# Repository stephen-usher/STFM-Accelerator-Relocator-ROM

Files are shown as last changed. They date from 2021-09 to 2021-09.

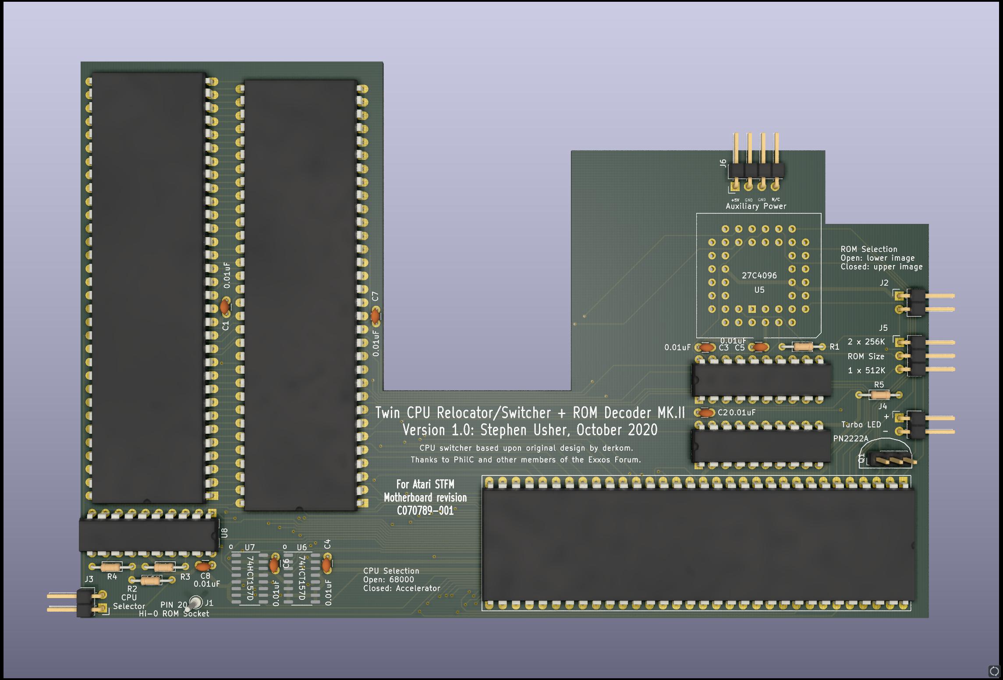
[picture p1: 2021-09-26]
STFM-TF536-Relocator+ROM-MkII.jpg

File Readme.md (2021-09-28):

This project is a PCB to allow two CPU sockets to be switched between on an
Atari ST.

It also provides a socket for a 512K ROM which can either be presented as a
single image or switched between an upper or lower image along with the logic
required to enable the larger ROMs, such as TOS 2.06 on a standard machine.

The ROM switching circuit was borrowed from Derkom (on the Exxos Forum) which
he used on his re-locator/switcher board for his STacy project.

The two sockets are identical so either can hold any processor which runs in a
68000 socket. On mine I currently had a stock 68000 in the "68000" socket and
a TF536 in the "Accelerator" one.

The ROM socket is compatible with the Exxos dual TOS ROMs.

P.S. There is another very important feature... there's a Turbo LED header,
which will light an LED if the "Accelerator" socket is in use.

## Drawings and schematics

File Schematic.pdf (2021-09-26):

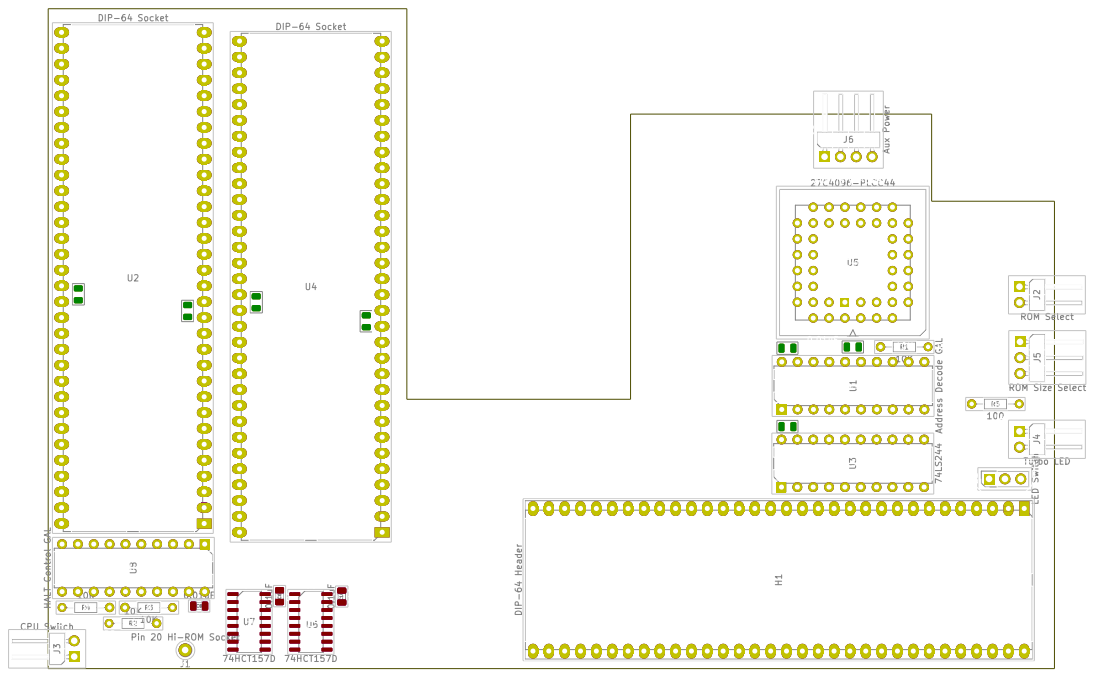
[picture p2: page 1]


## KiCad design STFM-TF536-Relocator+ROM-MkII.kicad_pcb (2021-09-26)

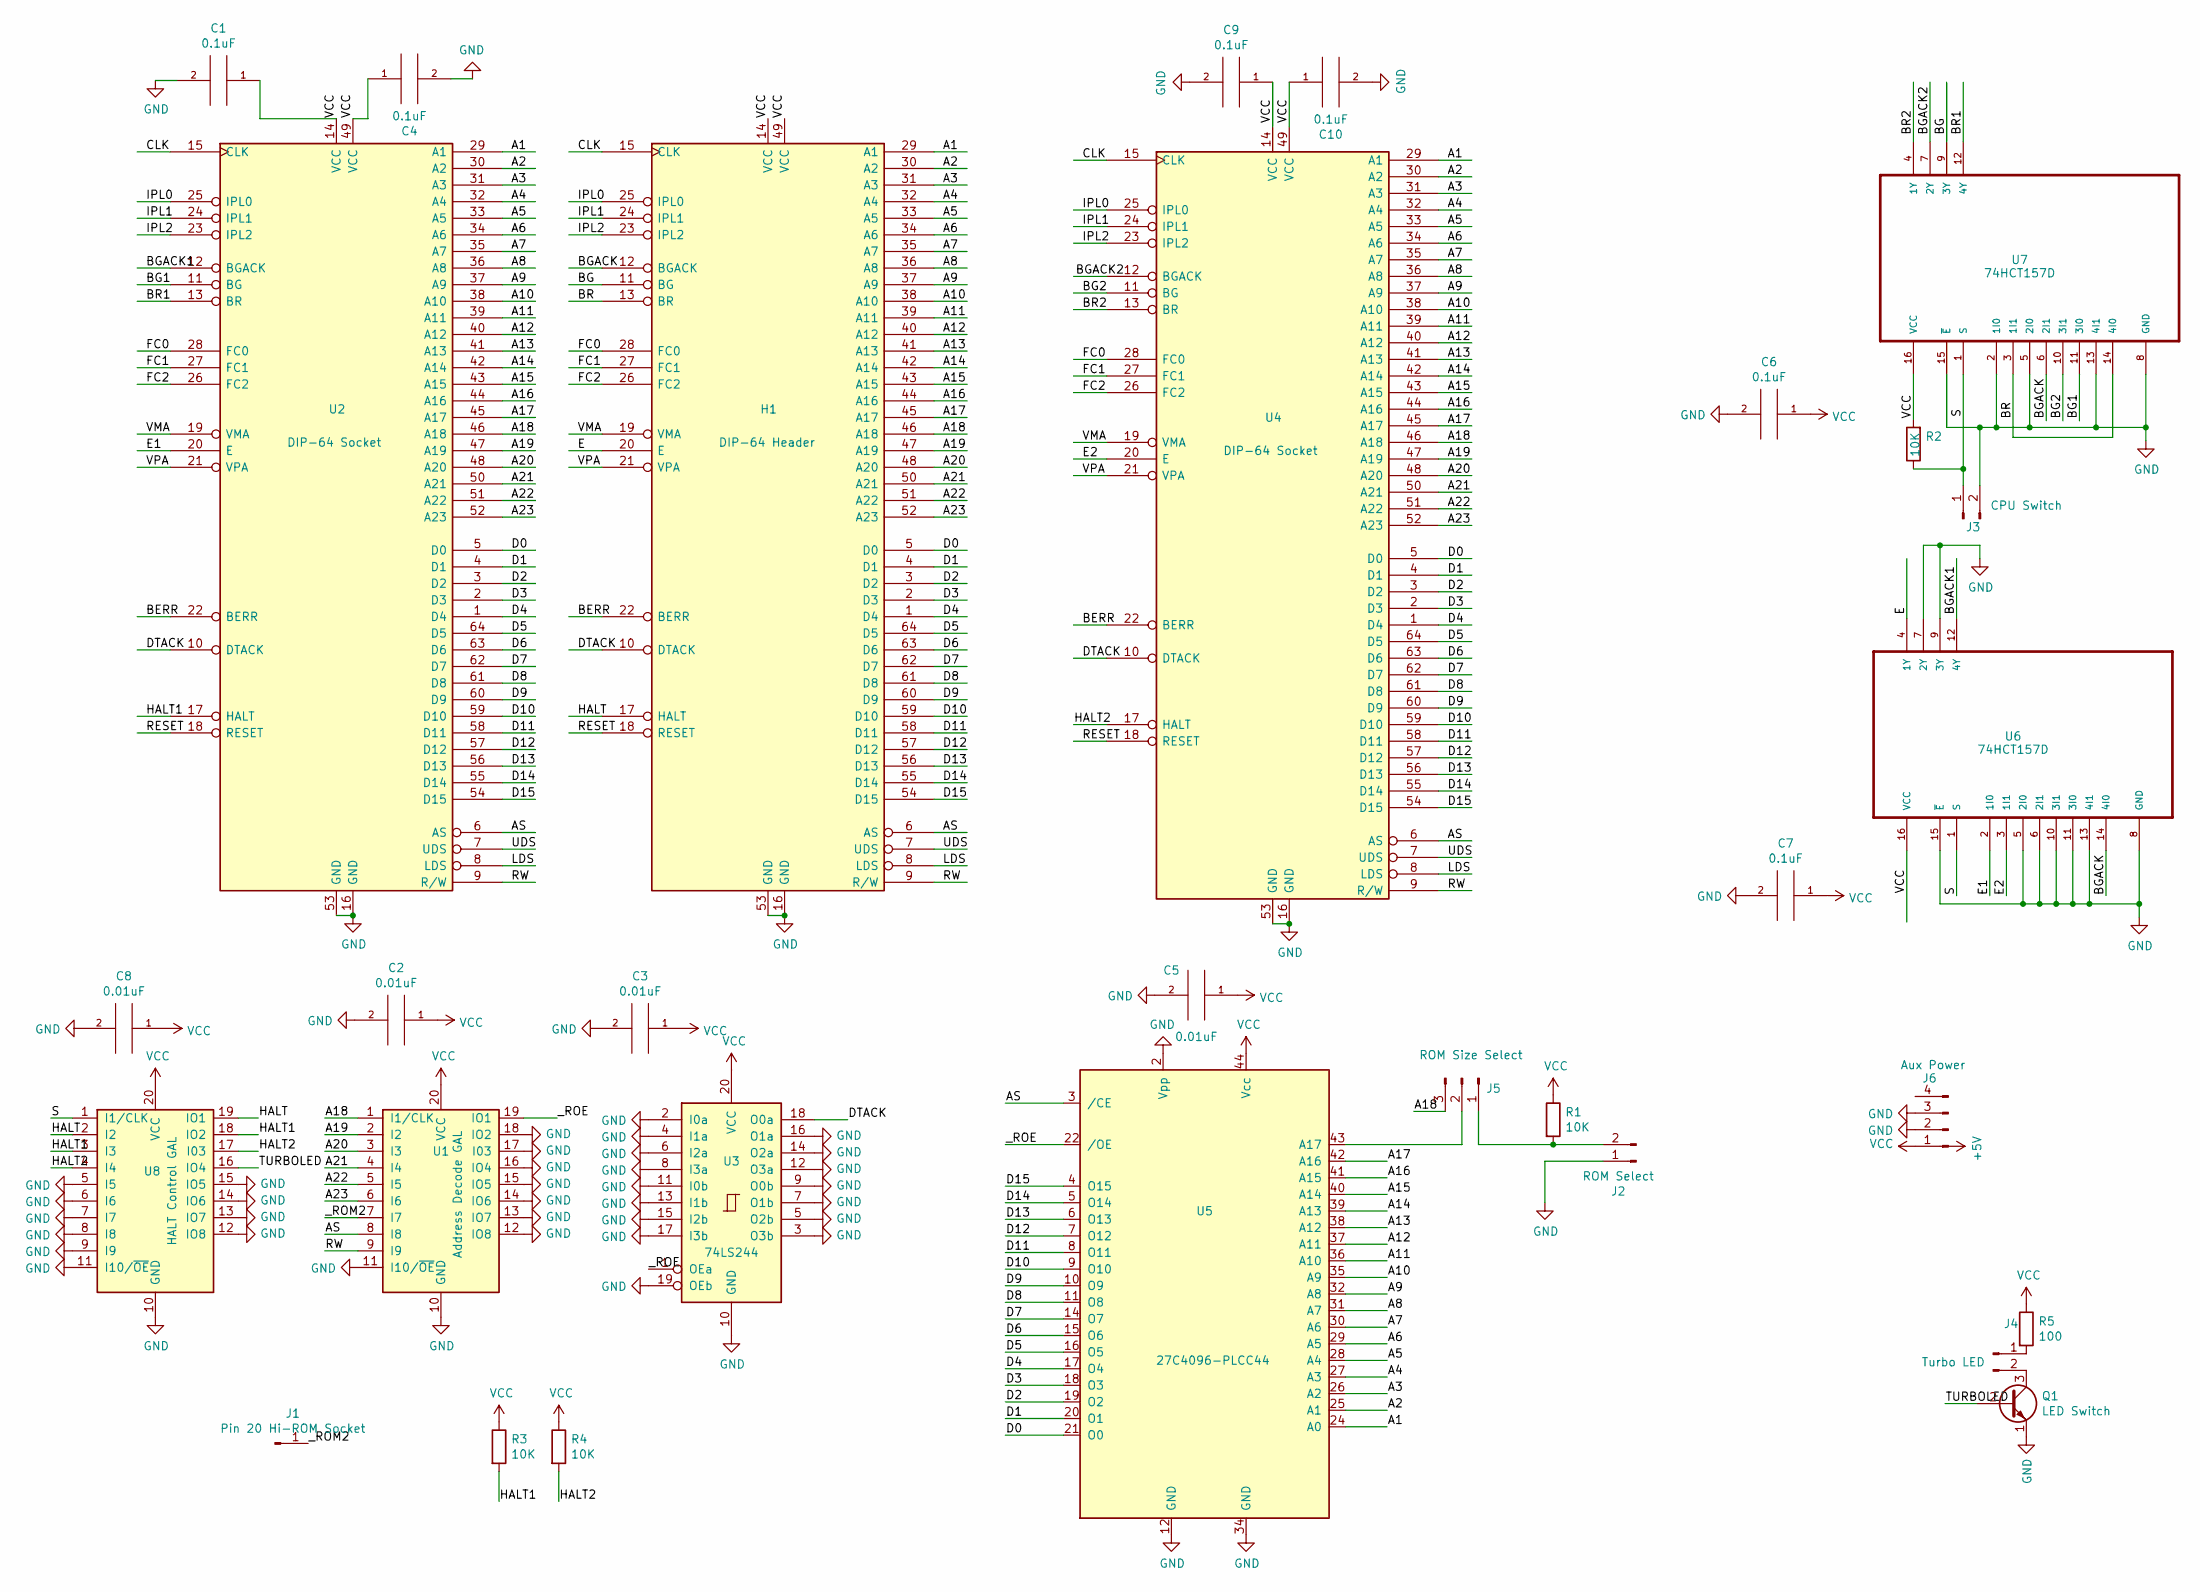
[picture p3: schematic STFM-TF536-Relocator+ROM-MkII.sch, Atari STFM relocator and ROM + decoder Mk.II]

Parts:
C1, C4, C6, C7, C9, C10: 0.1uF; C_0805_2012Metric
C2, C3, C5, C8: 0.01uF; C_0805_2012Metric
H1: DIP-64 Header; DIP-64_W22.86mm_Socket_LongPads
J1: Pin 20 Hi-ROM Socket; Pin_D1.0mm_L10.0mm
J2: ROM Select; PinHeader_1x02_P2.54mm_Horizontal
J3: CPU Switch; PinHeader_1x02_P2.54mm_Horizontal
J4: Turbo LED; PinHeader_1x02_P2.54mm_Horizontal
J5: ROM Size Select; PinHeader_1x03_P2.54mm_Horizontal
J6: Aux Power; PinHeader_1x04_P2.54mm_Horizontal
Q1: LED Switch; PinHeader_1x03_P2.54mm_Vertical
R1, R2, R3, R4: 10K; R_Axial_DIN0204_L3.6mm_D1.6mm_P7.62mm_Horizontal
R5: 100; R_Axial_DIN0204_L3.6mm_D1.6mm_P7.62mm_Horizontal
U1: Address Decode GAL; DIP-20_W7.62mm
U2, U4: DIP-64 Socket; DIP-64_W22.86mm_LongPads
U3: 74LS244; DIP-20_W7.62mm
U5: 27C4096-PLCC44; PLCC-44_THT-Socket
U6, U7: 74HCT157D; SO-16_3.9x9.9mm_P1.27mm
U8: HALT Control GAL; DIP-20_W7.62mm

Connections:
/A1: H1.29 (A1), U2.29 (A1), U4.29 (A1), U5.24 (A0)
/A2: H1.30 (A2), U2.30 (A2), U4.30 (A2), U5.25 (A1)
/A3: H1.31 (A3), U2.31 (A3), U4.31 (A3), U5.26 (A2)
/A4: H1.32 (A4), U2.32 (A4), U4.32 (A4), U5.27 (A3)
/A5: H1.33 (A5), U2.33 (A5), U4.33 (A5), U5.28 (A4)
/A6: H1.34 (A6), U2.34 (A6), U4.34 (A6), U5.29 (A5)
/A7: H1.35 (A7), U2.35 (A7), U4.35 (A7), U5.30 (A6)
/A8: H1.36 (A8), U2.36 (A8), U4.36 (A8), U5.31 (A7)
/A9: H1.37 (A9), U2.37 (A9), U4.37 (A9), U5.32 (A8)
/A10: H1.38 (A10), U2.38 (A10), U4.38 (A10), U5.35 (A9)
/A11: H1.39 (A11), U2.39 (A11), U4.39 (A11), U5.36 (A10)
/A12: H1.40 (A12), U2.40 (A12), U4.40 (A12), U5.37 (A11)
/A13: H1.41 (A13), U2.41 (A13), U4.41 (A13), U5.38 (A12)
/A14: H1.42 (A14), U2.42 (A14), U4.42 (A14), U5.39 (A13)
/A15: H1.43 (A15), U2.43 (A15), U4.43 (A15), U5.40 (A14)
/A16: H1.44 (A16), U2.44 (A16), U4.44 (A16), U5.41 (A15)
/A17: H1.45 (A17), U2.45 (A17), U4.45 (A17), U5.42 (A16)
/A18: H1.46 (A18), J5.3, U1.1 (I1/CLK), U2.46 (A18), U4.46 (A18)
/A19: H1.47 (A19), U1.2 (I2), U2.47 (A19), U4.47 (A19)
/A20: H1.48 (A20), U1.3 (I3), U2.48 (A20), U4.48 (A20)
/A21: H1.50 (A21), U1.4 (I4), U2.50 (A21), U4.50 (A21)
/A22: H1.51 (A22), U1.5 (I5), U2.51 (A22), U4.51 (A22)
/A23: H1.52 (A23), U1.6 (I6), U2.52 (A23), U4.52 (A23)
/AS: H1.6 (AS), U1.8 (I8), U2.6 (AS), U4.6 (AS), U5.3 (/CE)
/BERR: H1.22 (BERR), U2.22 (BERR), U4.22 (BERR)
/BG: H1.11 (BG), U7.9 (3Y)
/BG1: U2.11 (BG), U7.11 (3I0)
/BG2: U4.11 (BG), U7.10 (3I1)
/BGACK: H1.12 (BGACK), U6.14 (4I0), U7.6 (2I1)
/BGACK1: U2.12 (BGACK), U6.12 (4Y)
/BGACK2: U4.12 (BGACK), U7.7 (2Y)
/BR: H1.13 (BR), U7.3 (1I1), U7.14 (4I0)
/BR1: U2.13 (BR), U7.12 (4Y)
/BR2: U4.13 (BR), U7.4 (1Y)
/CLK: H1.15 (CLK), U2.15 (CLK), U4.15 (CLK)
/D0: H1.5 (D0), U2.5 (D0), U4.5 (D0), U5.21 (O0)
/D1: H1.4 (D1), U2.4 (D1), U4.4 (D1), U5.20 (O1)
/D2: H1.3 (D2), U2.3 (D2), U4.3 (D2), U5.19 (O2)
/D3: H1.2 (D3), U2.2 (D3), U4.2 (D3), U5.18 (O3)
/D4: H1.1 (D4), U2.1 (D4), U4.1 (D4), U5.17 (O4)
/D5: H1.64 (D5), U2.64 (D5), U4.64 (D5), U5.16 (O5)
/D6: H1.63 (D6), U2.63 (D6), U4.63 (D6), U5.15 (O6)
/D7: H1.62 (D7), U2.62 (D7), U4.62 (D7), U5.14 (O7)
/D8: H1.61 (D8), U2.61 (D8), U4.61 (D8), U5.11 (O8)
/D9: H1.60 (D9), U2.60 (D9), U4.60 (D9), U5.10 (O9)
/D10: H1.59 (D10), U2.59 (D10), U4.59 (D10), U5.9 (O10)
/D11: H1.58 (D11), U2.58 (D11), U4.58 (D11), U5.8 (O11)
/D12: H1.57 (D12), U2.57 (D12), U4.57 (D12), U5.7 (O12)
/D13: H1.56 (D13), U2.56 (D13), U4.56 (D13), U5.6 (O13)
/D14: H1.55 (D14), U2.55 (D14), U4.55 (D14), U5.5 (O14)
/D15: H1.54 (D15), U2.54 (D15), U4.54 (D15), U5.4 (O15)
/DTACK: H1.10 (DTACK), U2.10 (DTACK), U3.18 (O0a), U4.10 (DTACK)
/E: H1.20 (E), U6.4 (1Y)
/E1: U2.20 (E), U6.2 (1I0)
/E2: U4.20 (E), U6.3 (1I1)
/FC0: H1.28 (FC0), U2.28 (FC0), U4.28 (FC0)
/FC1: H1.27 (FC1), U2.27 (FC1), U4.27 (FC1)
/FC2: H1.26 (FC2), U2.26 (FC2), U4.26 (FC2)
/HALT: H1.17 (HALT), U8.2 (I2), U8.19 (IO1)
/HALT1: R3.2, U2.17 (HALT), U8.3 (I3), U8.18 (IO2)
/HALT2: R4.2, U4.17 (HALT), U8.4 (I4), U8.17 (I03)
/IPL0: H1.25 (IPL0), U2.25 (IPL0), U4.25 (IPL0)
/IPL1: H1.24 (IPL1), U2.24 (IPL1), U4.24 (IPL1)
/IPL2: H1.23 (IPL2), U2.23 (IPL2), U4.23 (IPL2)
/LDS: H1.8 (LDS), U2.8 (LDS), U4.8 (LDS)
/RESET: H1.18 (RESET), U2.18 (RESET), U4.18 (RESET)
/RW: H1.9 (R/W), U1.9 (I9), U2.9 (R/W), U4.9 (R/W)
/S: J3.1, R2.1, U6.1 (S), U7.1 (S), U8.1 (I1/CLK)
/TURBOLED: Q1.2 (B), U8.16 (IO4)
/UDS: H1.7 (UDS), U2.7 (UDS), U4.7 (UDS)
/VMA: H1.19 (VMA), U2.19 (VMA), U4.19 (VMA)
/VPA: H1.21 (VPA), U2.21 (VPA), U4.21 (VPA)
/_ROE: U1.19 (IO1), U3.1 (OEa), U5.22 (/OE)
/_ROM2: J1.1, U1.7 (I7)
GND: C1.2, C2.2, C3.2, C4.2, C5.2, C6.2, C7.2, C8.2, C9.2, C10.2, H1.16 (GND), H1.53 (GND), J2.1, J3.2, J6.2, J6.3, Q1.1 (E), U1.10 (GND), U1.11 (I10/~OE~), U1.12 (IO8), U1.13 (IO7), U1.14 (IO6), U1.15 (IO5), U1.16 (IO4), U1.17 (I03), U1.18 (IO2), U2.16 (GND), U2.53 (GND), U3.2 (I0a), U3.3 (O3b), U3.4 (I1a), U3.5 (O2b), U3.6 (I2a), U3.7 (O1b), U3.8 (I3a), U3.9 (O0b), U3.10 (GND), U3.11 (I0b), U3.12 (O3a), U3.13 (I1b), U3.14 (O2a), U3.15 (I2b), U3.16 (O1a), U3.17 (I3b), U3.19 (OEb), U4.16 (GND), U4.53 (GND), U5.2 (Vpp), U5.12 (GND), U5.34 (GND), U6.5 (2I0), U6.6 (2I1), U6.7 (2Y), U6.8 (GND), U6.9 (3Y), U6.10 (3I1), U6.11 (3I0), U6.13 (4I1), U6.15 (~E), U7.2 (1I0), U7.5 (2I0), U7.8 (GND), U7.13 (4I1), U7.15 (~E), U8.5 (I5), U8.6 (I6), U8.7 (I7), U8.8 (I8), U8.9 (I9), U8.10 (GND), U8.11 (I10/~OE~), U8.12 (IO8), U8.13 (IO7), U8.14 (IO6), U8.15 (IO5)
unnamed: J2.2, J5.1, R1.2
unnamed: J4.1, R5.2
unnamed: J4.2, Q1.3 (C)
unnamed: J5.2, U5.43 (A17)
VCC: C1.1, C2.1, C3.1, C4.1, C5.1, C6.1, C7.1, C8.1, C9.1, C10.1, H1.14 (VCC), H1.49 (VCC), J6.1, R1.1, R2.2, R3.1, R4.1, R5.1, U1.20 (VCC), U2.14 (VCC), U2.49 (VCC), U3.20 (VCC), U4.14 (VCC), U4.49 (VCC), U5.44 (Vcc), U6.16 (VCC), U7.16 (VCC), U8.20 (VCC)

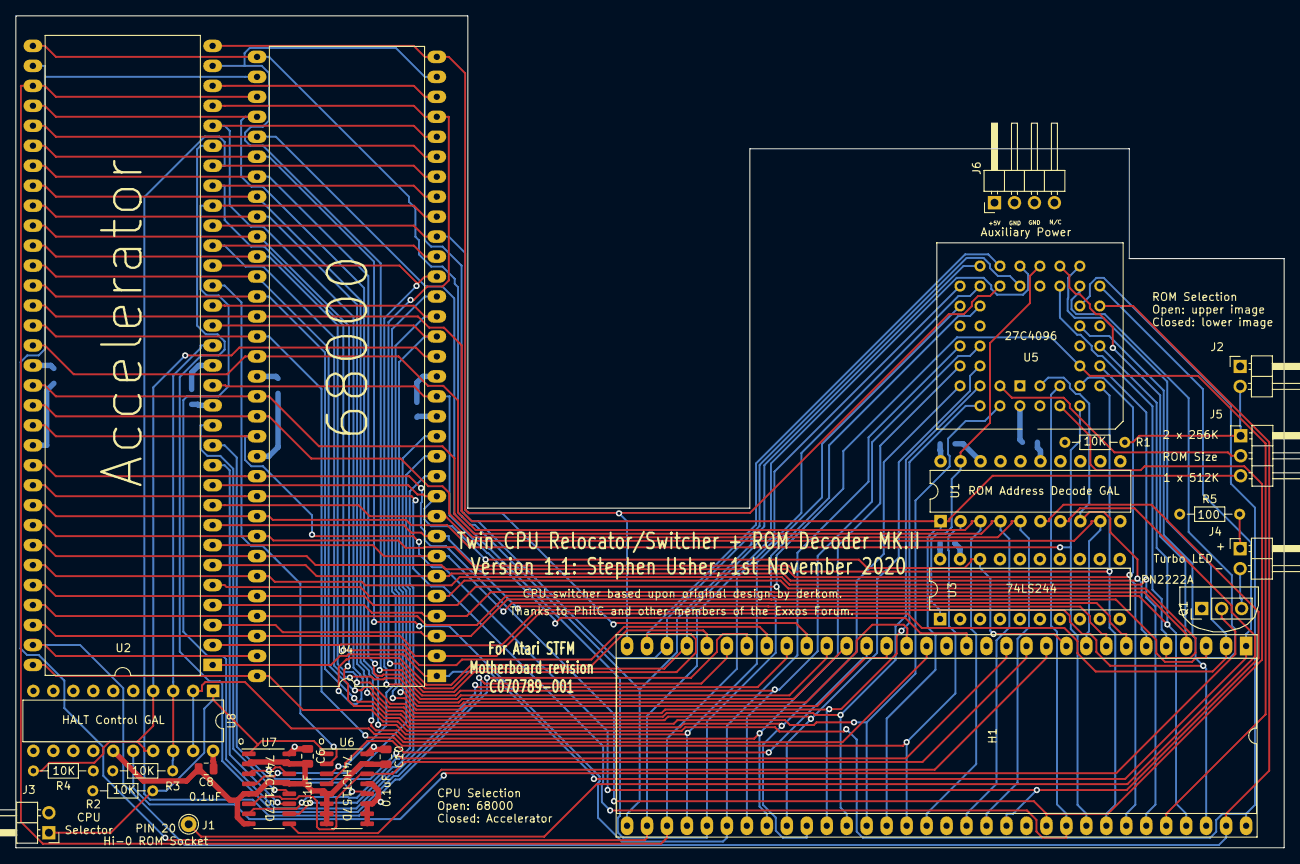
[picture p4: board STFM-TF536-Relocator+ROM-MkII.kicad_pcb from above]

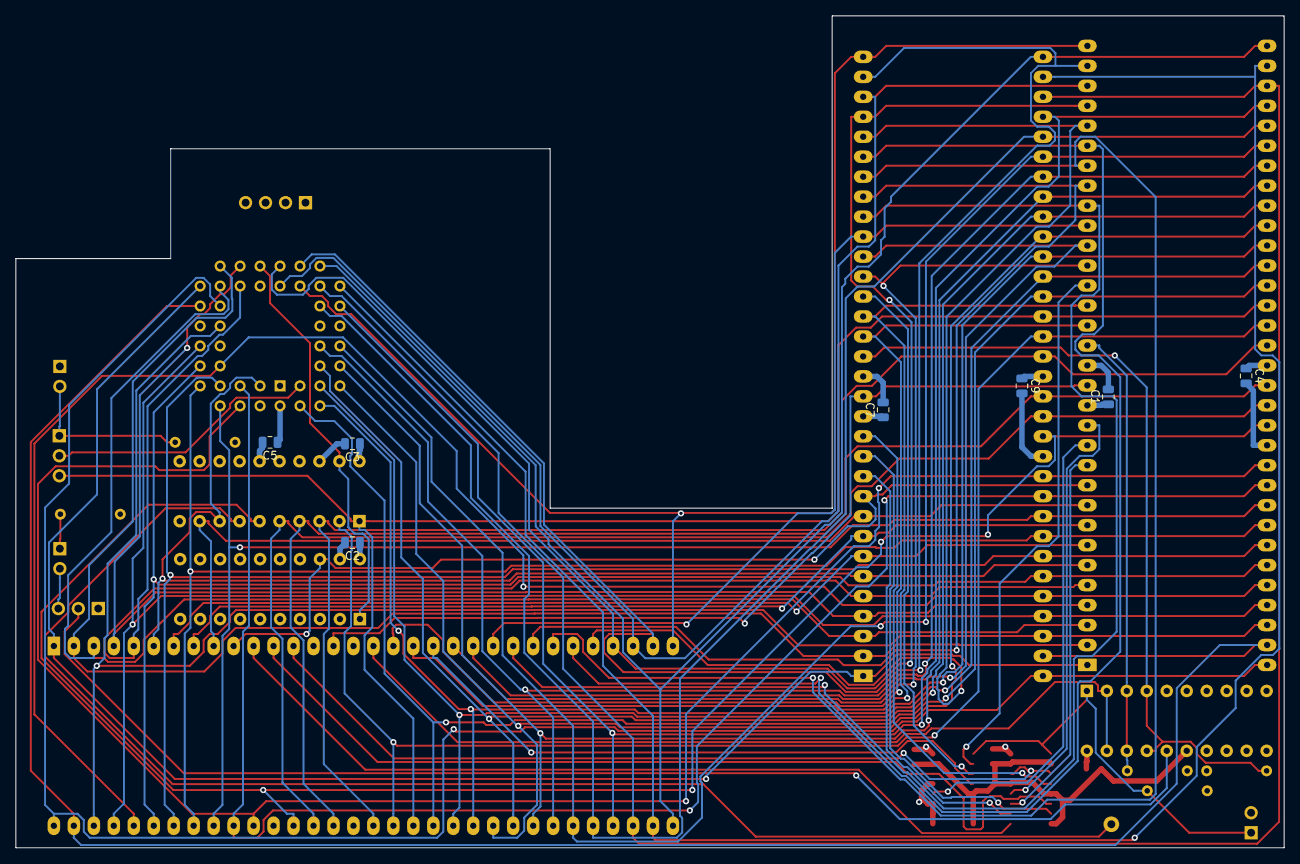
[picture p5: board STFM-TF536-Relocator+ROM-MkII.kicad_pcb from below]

Board: 4 copper layers, 161.3 x 105.8 mm, 31 parts (7 on the bottom side), 80 nets.
